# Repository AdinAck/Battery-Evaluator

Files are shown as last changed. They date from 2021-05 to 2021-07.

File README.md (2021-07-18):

# Battery-Evaluator
A comprehensive battery evaluator board for running simple tests and measurements, or creating a battery profile for accurately predicting charge level from voltage.







## Electrical Characteristics
- 0-5v battery (single cell)
- 0-1000mA programable constant current draw
- Do not reverse polarity of battery, the board will die
- While you *can* plug in a battery before USB is plugged in... you shouldn't

## Software Features
- Graph the measured and predicted battery voltage with respect to mAh consumed
- Measure ESR
- Measure mWh consumed
- Monitor temperature of FETs and resistors

## To Be Implemented
- More battery chemistries
- [Op-Amp oscillation fix](https://github.com/AdinAck/Battery-Evaluator/issues/1)
- Combine multiple constant current tests to make the ultimate battery profile
- Generate voltage, current -> percent charge function

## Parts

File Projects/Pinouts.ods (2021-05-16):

Pin ID | Type | Net
D5
D6
D9
D10
D11
D12
D13 | Dout | D13
D29
D21
A0 | DAC | MOS_SIGNAL
A1 |  | TEMP1
A2 | ADC | ~BATT
A3 | ADC | ~MOS_SOURCE
A4 |  | TEMP2
A5 | ADC | VREF
TX | UART | DATA_TX
RX | UART | DATA_RX
MOSI
MISO
SCK
D+ | USB | DEBUG_D+
D- | USB | DEBUG_D-
SWDIO | Flash
SWCLK | Flash

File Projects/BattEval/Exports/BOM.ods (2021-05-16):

Reference | Mouser Part Number | Manufacturer Name | Manufacturer Part Number | Mouser Price/Stock | Quantity
> C3, C5 | 06035A220JAT4A | AVX | 581-06035A220JAT4A | https://www.mouser.co.uk/ProductDetail/AVX/06035A220JAT4A/?qs=WmCxkUxNecQT6QFugq%2FgJA%3D%3D | 2
> C4, C7, C15 | 0603ZC105KAT2A | AVX | 581-0603ZC105KAT2A | https://www.mouser.com/Search/Refine.aspx?Keyword=581-0603ZC105KAT2A | 3
> C1, C2, C6, C8, C9, C12 | 06033C104KAT2A | AVX | 581-06033C104KAT2A | https://www.mouser.co.uk/ProductDetail/AVX/06033C104KAT2A/?qs=gPDEucxdFwYuZhv3uXRdIw%3D%3D | 6
> C10, C11 | 0603ZD106KAT4A | AVX | 581-0603ZD106KAT4A | https://www.mouser.co.uk/ProductDetail/AVX/0603ZD106KAT4A?qs=%252BdQmOuGyFcGtso703HlSDw%3D%3D | 2
> C13, C14 | 06033C470KAT2A | AVX | 581-06033C470KAT2A | http://www.mouser.com/Search/ProductDetail.aspx?qs=zRMn1EiLHUce0mcQKVYXJg%3d%3d | 2
C16 | TAJA475K010RNJV | AVX | 581-TAJA475K010RNJV | https://www.mouser.co.uk/ProductDetail/AVX/TAJA475K010RNJV?qs=VymPLiRQZITld0CPYYWYtw%3D%3D | 1
C17 | 0603ZC103KAT2A | AVX | 581-0603ZC103K | https://www.mouser.com/Search/Refine.aspx?Keyword=581-0603ZC103K | 1
> D1-D3 | MBR120VLSFT3G | ON Semiconductor | 863-MBR120VLSFT3G | https://www.mouser.co.uk/ProductDetail/ON-Semiconductor/MBR120VLSFT3G/?qs=3JMERSakebrD2yr9jFliaA%3D%3D | 3
FB1 | MI1206K601R-10 | Laird Technologies | N/A | https://www.mouser.com/Search/Refine.aspx?Keyword=N%2FA | 1
> H1, H2 | 960-23-12-D-AB-0 | Wakefield-Vette | 567-960-23-12-D-AB-0 | https://www.mouser.co.uk/ProductDetail/Wakefield-Vette/960-23-12-D-AB-0?qs=PqoDHHvF64%252BdCFngwMp09w%3D%3D | 2
IC1 | TLV9101IDBVR | Texas Instruments | 595-TLV9101IDBVR | https://www.mouser.co.uk/ProductDetail/Texas-Instruments/TLV9101IDBVR?qs=P1JMDcb91o6ZLUyc%2FHtrGA%3D%3D | 1
> IC2, IC3 | TMP235AEDBZRQ1 | Texas Instruments | 595-TMP235AEDBZRQ1 | https://www.mouser.co.uk/ProductDetail/Texas-Instruments/TMP235AEDBZRQ1/?qs=T3oQrply3y9acrBXtVPwnw%3D%3D | 2
IC4 | ATSAMD21G18A-MU | Microchip | 556-ATSAMD21G18A-MU | https://www.mouser.co.uk/ProductDetail/Microchip-Technology/ATSAMD21G18A-MU/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 | 1
IC5 | LM4040D25IDCKR | Texas Instruments | 595-LM4040D25IDCKR | https://www.mouser.co.uk/ProductDetail/Texas-Instruments/LM4040D25IDCKR?qs=paYhMW8qfivGgJ8gGFiCWw%3D%3D | 1
IC6 | FT230XS-U | FTDI Chip | 895-FT230XS-U | https://www.mouser.co.uk/ProductDetail/FTDI/FT230XS-U/?qs=Gp1Yz1mis3UZolxbXux7lw%3D%3D | 1
IC7 | SPX3819M5-L-3-3_TR | MaxLinear, Inc. | 701-SPX3819M5-L-33TR | https://www.mouser.co.uk/ProductDetail/MaxLinear/SPX3819M5-L-3-3-TR/?qs=S%2FCBhQS5rCp1Bb7a%252BD%2FCBQ%3D%3D | 1
J1 | M50-3600542 | Harwin | 855-M50-3600542 | https://www.mouser.co.uk/ProductDetail/Harwin/M50-3600542/?qs=9fQaSFfsqsz29hu1Jz0tTA%3D%3D | 1
J2 | XT60-M |  |  |  | 1
> J3, J4 | 47346-0001 | Molex | 538-47346-0001 | https://www.mouser.co.uk/ProductDetail/Molex/47346-0001/?qs=c2CV6XM0DweJBWaSeyWeCw%3D%3D | 2
LED1 | APT1608LSECK_J3-PRV | Kingbright | 604-APT1608LSECKJ3RV | https://www.mouser.co.uk/ProductDetail/Kingbright/APT1608LSECK-J3-PRV?qs=6oMev5NRZMFBN%252BbFaEKqAQ%3D%3D | 1
LED2 | 150060AS75000 | Wurth Elektronik | 710-150060AS75000 | https://www.mouser.co.uk/ProductDetail/Wurth-Elektronik/150060AS75000/?qs=d0WKAl%252BL4KbvMBYryeof0Q%3D%3D | 1
> Q1-Q4 | PH2925U,115 | Nexperia | 771-PH2925U115 | https://www.mouser.co.uk/ProductDetail/Nexperia/PH2925U115?qs=LOCUfHb8d9vnFm%2FhT%252Bjztw%3D%3D | 4
> R1, R17, R19, R22 | ERJ-S02F1002X | Panasonic | 667-ERJ-S02F1002X | https://www.mouser.co.uk/ProductDetail/Panasonic/ERJ-S02F1002X?qs=Zyl8A9hlmJre8ZnVBnn2RQ%3D%3D | 4
> R3, R16, R18 | RC0402FR-075KL | YAGEO (PHYCOMP) | 603-RC0402FR-075KL | https://www.mouser.co.uk/ProductDetail/Yageo/RC0402FR-075KL/?qs=9h0bZHM%2F3zL5adZvfm%252BR4Q%3D%3D | 3
> R4-R15 | CRGP2512F12R | TE Connectivity | 279-CRGP2512F12R | https://www.mouser.co.uk/ProductDetail/TE-Connectivity-Holsworthy/CRGP2512F12R/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 | 12
R20 | ERJ-U02F1001X | Panasonic | 667-ERJ-U02F1001X | https://www.mouser.com/Search/Refine.aspx?Keyword=667-ERJ-U02F1001X | 1
> R21, R26 | ERJ-2RKF7500X | Panasonic | 667-ERJ-2RKF7500X | https://www.mouser.com/Search/Refine.aspx?Keyword=667-ERJ-2RKF7500X | 2
R23 | ERJ-U02F1003X | Panasonic | 667-ERJ-U02F1003X | https://www.mouser.com/Search/Refine.aspx?Keyword=667-ERJ-U02F1003X | 1
> R2, R24, R25, R27, R28 | ERJ2RKD27R0X | Panasonic | 667-ERJ-2RKD27R0X | https://www.mouser.com/Search/Refine.aspx?Keyword=667-ERJ-2RKD27R0X | 5
S1 | EVQ-P9W02M | Panasonic | 667-EVQ-P9W02M | https://www.mouser.co.uk/ProductDetail/Panasonic/EVQ-P9W02M?qs=PzGy0jfpSMsvy2xbnzB8PQ%3D%3D | 1
> TP1-TP5 | TestPoint_Probe |  |  |  | 5
Y1 | CM7V-T1A-32.768kHz-6pF-20PPM-TA-QC | Micro Crystal AG | 428-201843-MG01 | https://www.mouser.co.uk/ProductDetail/Micro-Crystal/CM7V-T1A-32768kHz-6pF-20PPM-TA-QC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 | 1

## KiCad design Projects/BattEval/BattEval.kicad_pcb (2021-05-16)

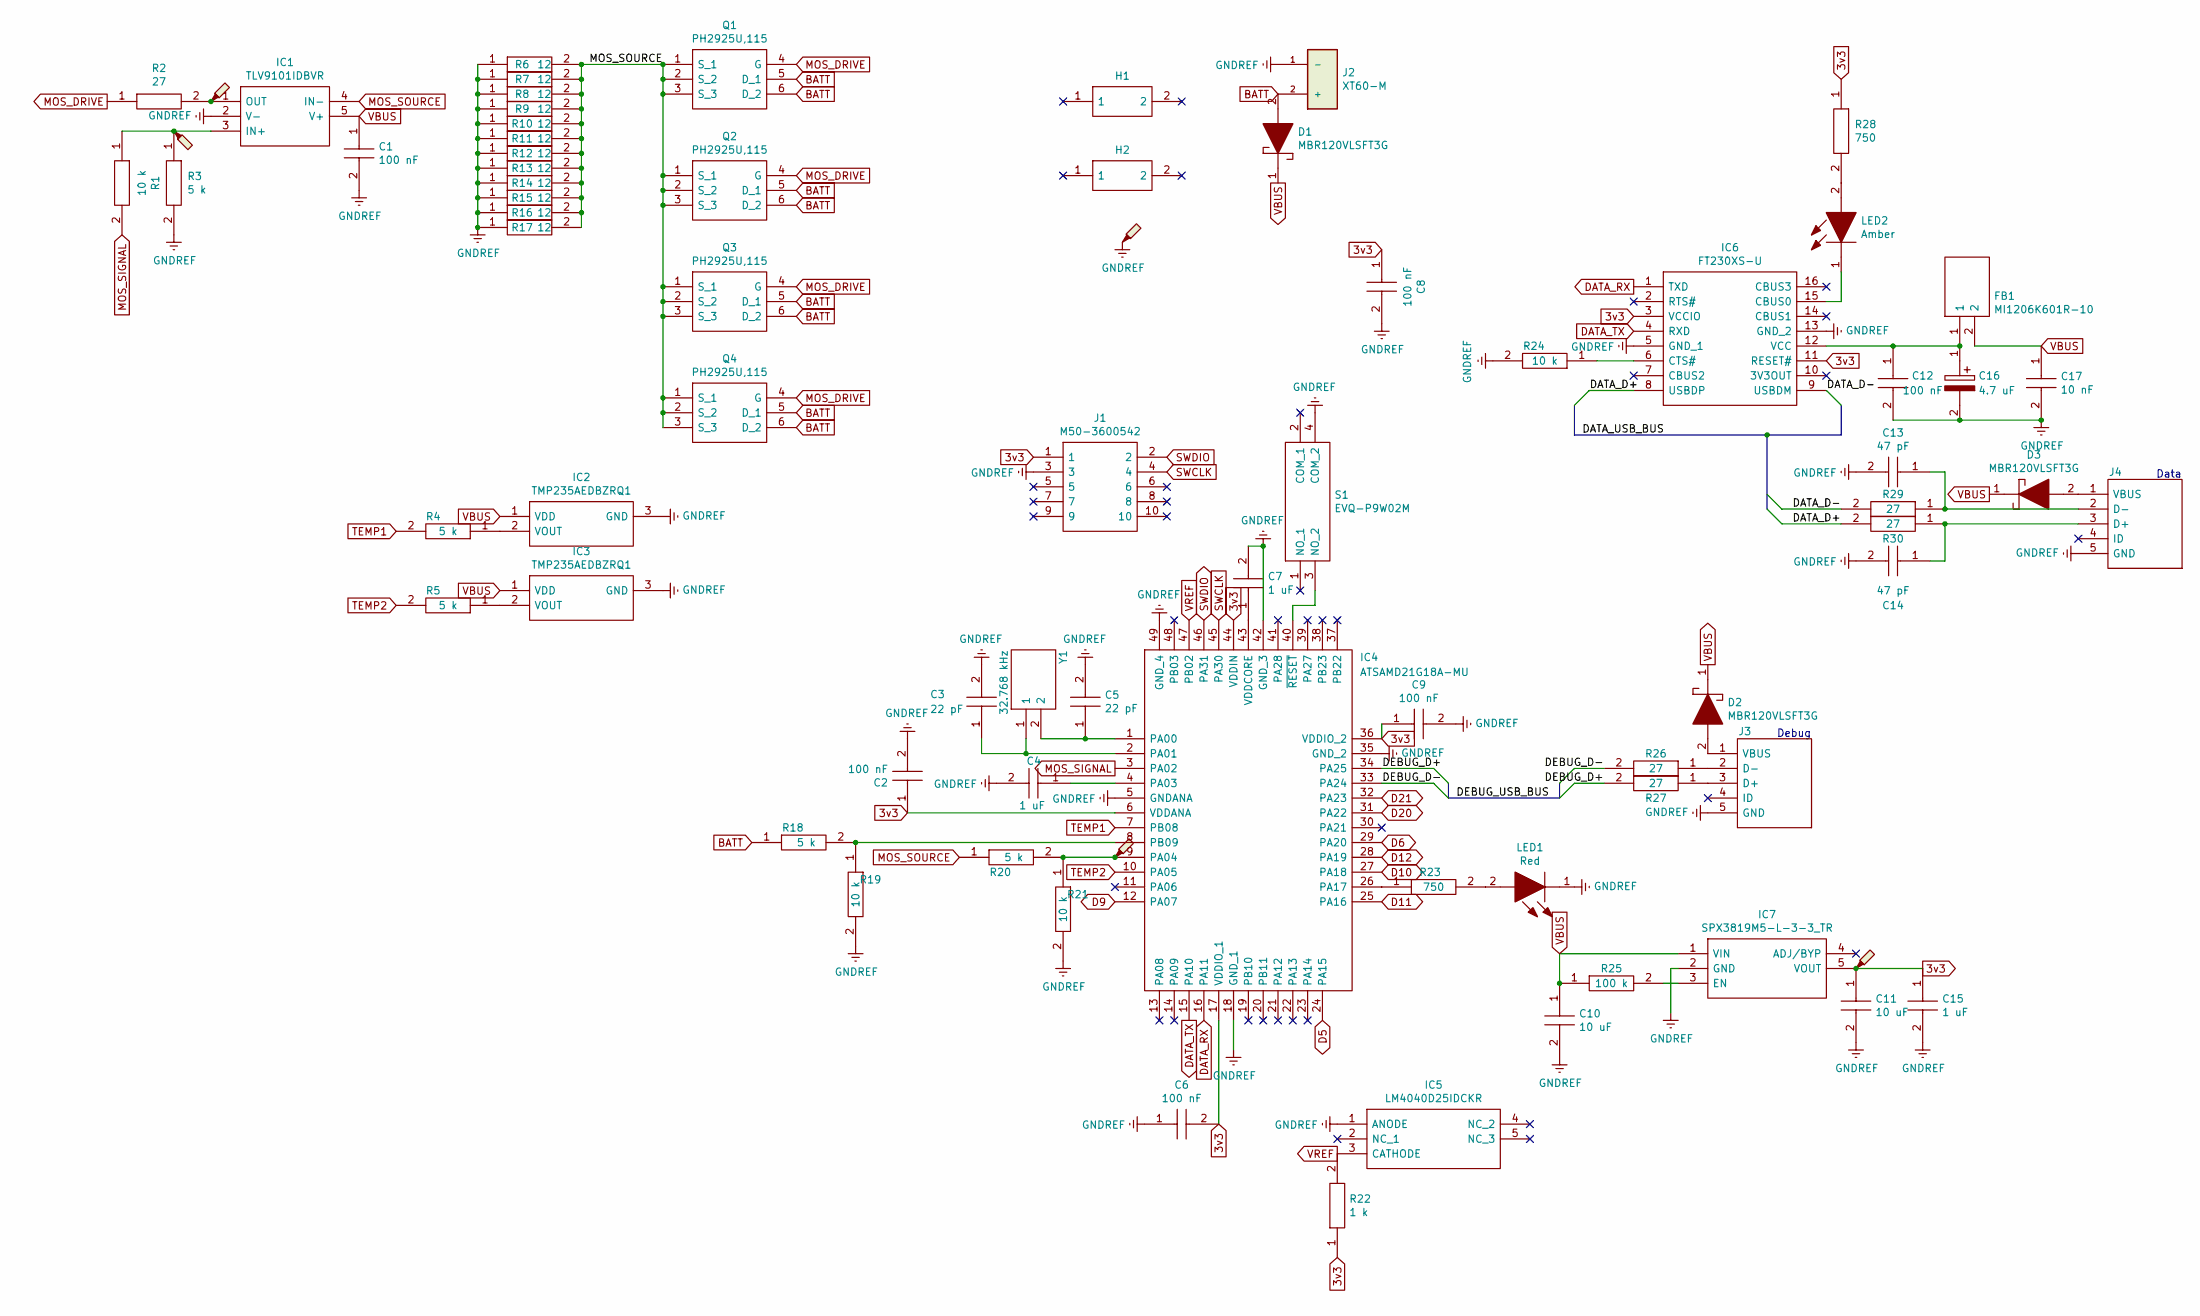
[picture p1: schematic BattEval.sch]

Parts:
C1, C2, C6, C8, C9, C12: 06033C104KAT2A; CAPC1608X90N; Mouser Part Number 581-06033C104KAT2A
C3, C5: 06035A220JAT4A; CAPC1608X90N; Mouser Part Number 581-06035A220JAT4A
C4, C7, C15: 0603ZC105KAT2A; CAPC1608X90N; Mouser Part Number 581-0603ZC105KAT2A
C10, C11: 0603ZD106KAT4A; CAPC1608X90N; Mouser Part Number 581-0603ZD106KAT4A
C13, C14: 06033C470KAT2A; CAPC1608X90N; Mouser Part Number 581-06033C470KAT2A
C16: TAJA475K010RNJV; CAPPM3216X180N; Mouser Part Number 581-TAJA475K010RNJV
C17: 0603ZC103KAT2A; CAPC1608X90N; Mouser Part Number 581-0603ZC103K
D1, D2, D3: MBR120VLSFT3G; SODFL3616X98N; Mouser Part Number 863-MBR120VLSFT3G
FB1: MI1206K601R-10; BEADC3216X130N; Mouser Part Number N/A
H1, H2: 960-23-12-D-AB-0; 9602312DAB0; Mouser Part Number 567-960-23-12-D-AB-0
IC1: TLV9101IDBVR; SOT95P280X145-5N; Mouser Part Number 595-TLV9101IDBVR
IC2, IC3: TMP235AEDBZRQ1; SOT95P237X112-3N; Mouser Part Number 595-TMP235AEDBZRQ1
IC4: ATSAMD21G18A-MU; QFN50P700X700X90-49N-D; Mouser Part Number 556-ATSAMD21G18A-MU
IC5: LM4040D25IDCKR; SOT65P210X110-5N; Mouser Part Number 595-LM4040D25IDCKR
IC6: FT230XS-U; SOP64P599X175-16N; Mouser Part Number 895-FT230XS-U
IC7: SPX3819M5-L-3-3_TR; SOT95P280X145-5N; Mouser Part Number 701-SPX3819M5-L-33TR
J1: M50-3600542; M503600542; Mouser Part Number 855-M50-3600542
J2: XT60-M; AMASS_XT60-M; PARTREV 1.2
J3, J4: 47346-0001; Mouser Part Number 538-47346-0001
LED1: APT1608LSECK_J3-PRV; APT1608CGCK; Mouser Part Number 604-APT1608LSECKJ3RV
LED2: 150060AS75000; LEDC1608X80N; Mouser Part Number 710-150060AS75000
Q1, Q2, Q3, Q4: PH2925U,115; PSMN5R660YLX; Mouser Part Number 771-PH2925U115
R1, R19, R21, R24: ERJ-S02F1002X; RESC1005X40N; Mouser Part Number 667-ERJ-S02F1002X
R2, R26, R27, R29, R30: ERJ2RKD27R0X; RESC1005X40N; Mouser Part Number 667-ERJ-2RKD27R0X
R3, R4, R5, R18, R20: RC0402FR-075KL; RESC1005X40N; Mouser Part Number 603-RC0402FR-075KL
R6, R7, R8, R9, R10, R11, R12, R13, R14, R15, R16, R17: CRGP2512F12R; RESC6432X65N; Mouser Part Number 279-CRGP2512F12R
R22: ERJ-U02F1001X; RESC1005X40N; Mouser Part Number 667-ERJ-U02F1001X
R23, R28: ERJ-2RKF7500X; RESC1005X40N; Mouser Part Number 667-ERJ-2RKF7500X
R25: ERJ-U02F1003X; RESC1005X40N; Mouser Part Number 667-ERJ-U02F1003X
S1: EVQ-P9W02M; EVQP9W02M; Mouser Part Number 667-EVQ-P9W02M
TP1, TP2, TP3, TP4, TP5: TestPoint_Probe; Standard_Probe_Point
Y1: CM7V-T1A-32.768kHz-6pF-20PPM-TA-QC; CM7VT1A32768kHz6pF20PPMTAQC; Mouser Part Number 428-201843-MG01

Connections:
3v3: C2.1, C6.2, C8.1, C9.1, C11.1, C15.1, IC4.6 (VDDANA), IC4.17 (VDDIO_1), IC4.36 (VDDIO_2), IC4.44 (VDDIN), IC6.3 (VCCIO), IC6.11 (RESET#), IC7.5 (VOUT), J1.1, R22.1, R28.1, TP5.1
/DATA_D+: IC6.8 (USBDP), R30.2
/DATA_D-: IC6.9 (USBDM), R29.2
/DEBUG_D+: IC4.34 (PA25), R27.2
/DEBUG_D-: IC4.33 (PA24), R26.2
BATT: D1.2, J2.2 (+), Q1.5 (D_1), Q1.6 (D_2), Q2.5 (D_1), Q2.6 (D_2), Q3.5 (D_1), Q3.6 (D_2), Q4.5 (D_1), Q4.6 (D_2), R18.1
D5: IC4.24 (PA15)
D6: IC4.29 (PA20)
D9: IC4.12 (PA07)
D10: IC4.27 (PA18)
D11: IC4.25 (PA16)
D12: IC4.28 (PA19)
D20: IC4.31 (PA22)
D21: IC4.32 (PA23)
DATA_RX: IC4.16 (PA11), IC6.1 (TXD)
DATA_TX: IC4.15 (PA10), IC6.4 (RXD)
GNDREF: C1.2, C2.2, C3.2, C4.2, C5.2, C6.1, C7.2, C8.2, C9.2, C10.2, C11.2, C12.2, C13.2, C14.2, C15.2, C16.2, C17.2, IC1.2 (V-), IC2.3 (GND), IC3.3 (GND), IC4.5 (GNDANA), IC4.18 (GND_1), IC4.35 (GND_2), IC4.42 (GND_3), IC4.49 (GND_4), IC5.1 (ANODE), IC6.5 (GND_1), IC6.13 (GND_2), IC7.2 (GND), J1.3, J2.1 (-), J3.5 (GND), J4.5 (GND), LED1.1, R3.2, R6.1, R7.1, R8.1, R9.1, R10.1, R11.1, R12.1, R13.1, R14.1, R15.1, R16.1, R17.1, R19.2, R21.2, R24.2, S1.4 (COM_2), TP4.1
MOS_DRIVE: Q1.4 (G), Q2.4 (G), Q3.4 (G), Q4.4 (G), R2.1
MOS_SIGNAL: IC4.3 (PA02), R1.2
MOS_SOURCE: IC1.4 (IN-), Q1.1 (S_1), Q1.2 (S_2), Q1.3 (S_3), Q2.1 (S_1), Q2.2 (S_2), Q2.3 (S_3), Q3.1 (S_1), Q3.2 (S_2), Q3.3 (S_3), Q4.1 (S_1), Q4.2 (S_2), Q4.3 (S_3), R6.2, R7.2, R8.2, R9.2, R10.2, R11.2, R12.2, R13.2, R14.2, R15.2, R16.2, R17.2, R20.1
unnamed: C3.1, IC4.2 (PA01), Y1.1
unnamed: C4.1, IC4.4 (PA03)
unnamed: C5.1, IC4.1 (PA00), Y1.2
unnamed: C7.1, IC4.43 (VDDCORE)
unnamed: C12.1, C16.1, FB1.1, IC6.12 (VCC)
unnamed: C13.1, J4.2 (D-), R29.1
unnamed: C14.1, J4.3 (D+), R30.1
unnamed: D2.2, J3.1 (VBUS)
unnamed: D3.2, J4.1 (VBUS)
unnamed: IC1.1 (OUT), R2.2, TP2.1
unnamed: IC1.3 (IN+), R1.1, R3.1, TP1.1
unnamed: IC2.2 (VOUT), R4.1
unnamed: IC3.2 (VOUT), R5.1
unnamed: IC4.8 (PB09), R18.2, R19.1
unnamed: IC4.9 (PA04), R20.2, R21.1, TP3.1
unnamed: IC4.26 (PA17), R23.1
unnamed: IC4.40 (~RESET), S1.3 (NO_2)
unnamed: IC6.6 (CTS#), R24.1
unnamed: IC6.15 (CBUS0), LED2.1
unnamed: IC7.3 (EN), R25.2
unnamed: J3.2 (D-), R26.1
unnamed: J3.3 (D+), R27.1
unnamed: LED1.2, R23.2
unnamed: LED2.2, R28.2
SWCLK: IC4.45 (PA30), J1.4
SWDIO: IC4.46 (PA31), J1.2
TEMP1: IC4.7 (PB08), R4.2
TEMP2: IC4.10 (PA05), R5.2
VBUS: C1.1, C10.1, C17.1, D1.1, D2.1, D3.1, FB1.2, IC1.5 (V+), IC2.1 (VDD), IC3.1 (VDD), IC7.1 (VIN), R25.1
VREF: IC4.47 (PB02), IC5.3 (CATHODE), R22.2

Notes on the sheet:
Debug
Data

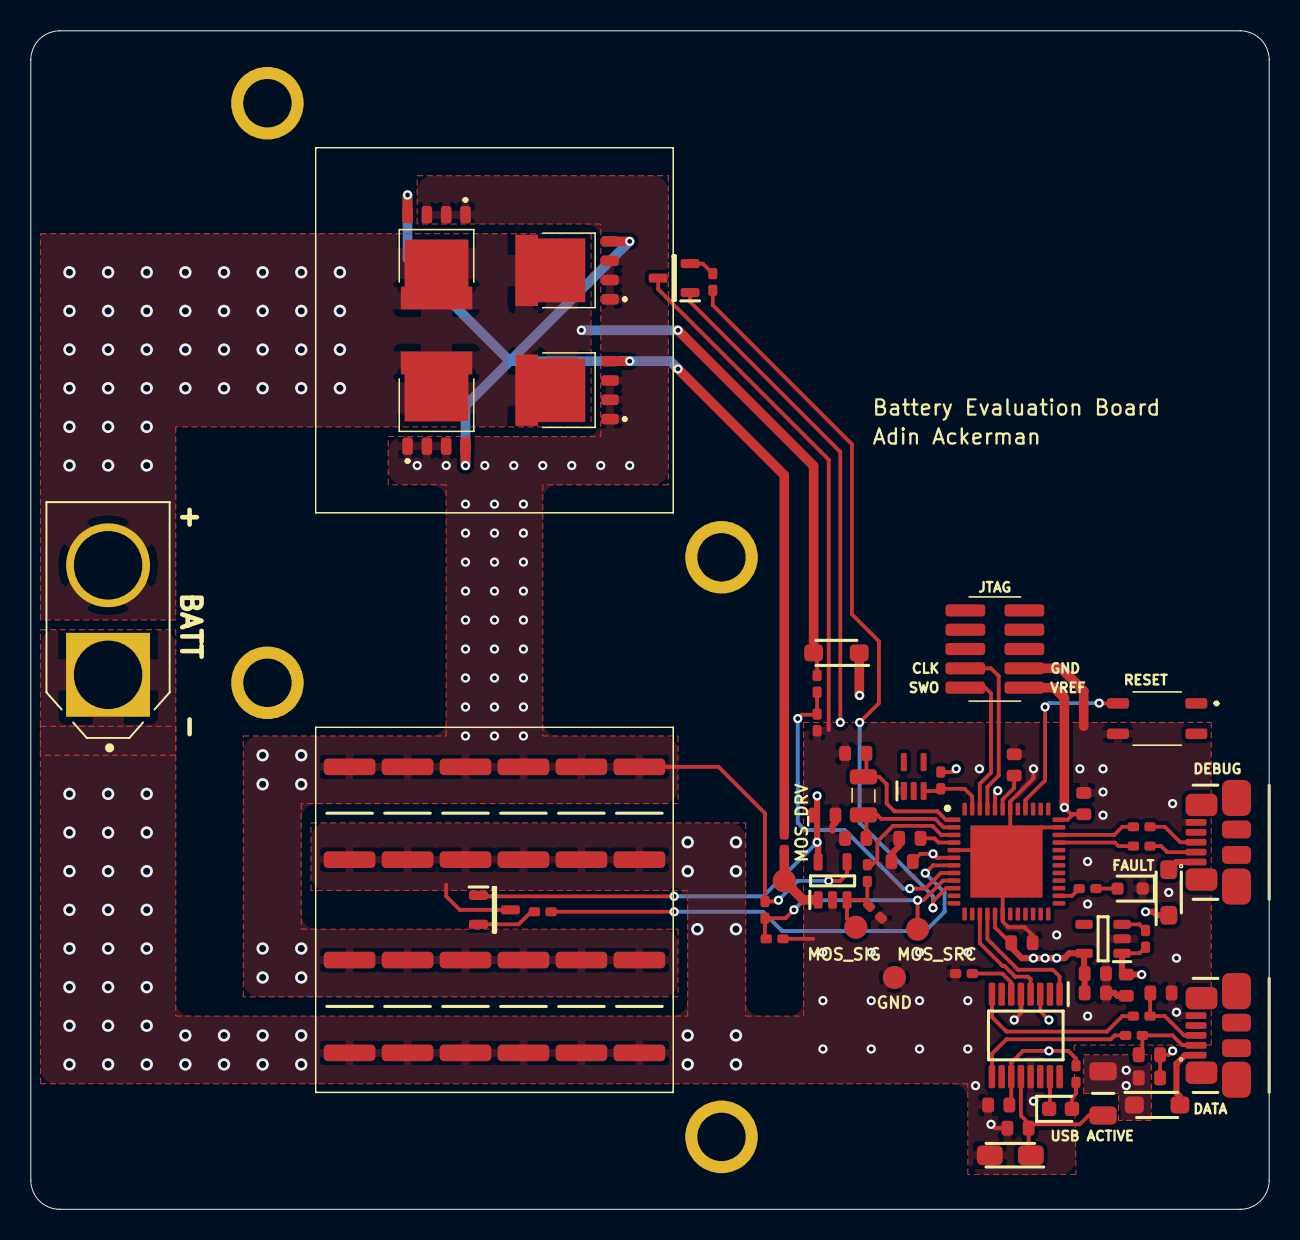
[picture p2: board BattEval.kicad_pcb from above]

Board: 2 copper layers, 81.4 x 77.5 mm, 77 parts (1 on the bottom side), 42 nets.

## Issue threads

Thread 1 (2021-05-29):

Op-Amp Oscillation Fix

AdinAck, 2021-05-29:
- Add 100nF capacitor from OUT to IN-
- Add 220 Ohm resistor from IN- to MOS_SOURCE

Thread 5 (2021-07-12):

Thermal throttle

AdinAck, 2021-07-12:
I recently discovered that lithium batteries can in fact overheat the MOSFETs if the target current is high enough, so I need to add thermal throttling.

I should implement thermal throttling board-side to ensure that if for whatever reason the client stops working, the board will not catch on fire.

The client should of course be informed when thermal throttling occurs so it can be displayed to the user.

While on the topic of temperature, maybe a "high ambient temperature" warning would be nice as well.

AdinAck, 2021-07-14:
Integrated thermal throttling and high ambient temperature warning added in eb28f56820dc9e42cb6b371c12010c0a3b3db2d6.

AdinAck, 2021-07-15:
Fully implemented.

Added warnings in 1a29615d5b73f9eea2b5b29dc64983564c6e26e0.

Closed 2021-07-15.

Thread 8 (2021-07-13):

Temperature sensor has frequent errors

AdinAck, 2021-07-13:
The temperature sensor's reading will frequently dip by a few degrees for a single measurement... why?

AdinAck, 2021-07-14:
Resolved by returning median of sample measurements rather than each measurement in eb28f56820dc9e42cb6b371c12010c0a3b3db2d6.

Closed 2021-07-14.

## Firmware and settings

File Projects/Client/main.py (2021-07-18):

"""
Battery Evaluator Client

This code is garbage, do not replicate for your own good.

Yours truly,
Adin Ackerman
"""

import threading
import serial
from serial.tools import list_ports
from serial.serialutil import SerialException
from tkinter import messagebox
from tkinter import *
from tkinter.ttk import *
import matplotlib.pyplot as plt
from matplotlib.backends.backend_tkagg import FigureCanvasTkAgg
from queue import Queue
from time import time, time_ns, sleep
from datetime import timedelta
from typing import *

COMMAND_DICT = {
    "batt-voltage": 0x10,
    "current": 0x11,
    # 'temp1': 0x12,
    "temp2": 0x13,
    "set-current": 0x20,
    "set-power": 0x21,
}

BATT_CHEMS = {"Lithium": (3, 4.1), "Alkaline": (1.2, 1.5), "Custom": (5, 5)}

THROTTLE_TEMP = 50
SHUTDOWN_TEMP = 60

tasksReady = threading.Condition()
taskQueue = Queue()


class TaskResult:
    value: Any = None


def ioTask(f):
    def inner(*args):
        condition = threading.Condition()
        result = TaskResult()
        with tasksReady:
            tasksReady.notify()

        with condition:
            taskQueue.put((result, condition, lambda: f(*args)))
            condition.wait()

        return result.value

    return inner


def ioLoop():
    while True:
        r, c, task = taskQueue.get()
        try:
            r.value = task()
        except SerialException:
            msg = "Communication interrupted."
            messagebox.showerror("Error", msg)
            updateStatus("[ERROR] " + msg)
            disconnect()
        with c:
            c.notify()


class SerCom:
    connected = False
    ports = {
        str(d.description): d for d in list_ports.comports() if d.description != "n/a"
    }

    def connect(self, comport: str) -> None:
        self.com = serial.Serial(self.ports[comport].device, 9600)
        self.connected = True

    def close(self):
        self.com.close()
        self.conected = False

    @property
    @ioTask
    def battVoltage(self) -> float:
        self.com.write(bytes([COMMAND_DICT["batt-voltage"], 0]))
        msgLen = int.from_bytes(self.com.read(1), "big")
        battv = self.com.read(msgLen).decode()
        battv = round(float(battv), 3)

        return battv

    @property
    @ioTask
    def battCurrent(self) -> float:
        self.com.write(bytes([COMMAND_DICT["current"], 0]))
        msgLen = int.from_bytes(self.com.read(1), "big")
        current = self.com.read(msgLen).decode()
        current = int(round(float(current) * 1000, 3))  # mA

        return current

    @battCurrent.setter
    @ioTask
    def battCurrent(self, value: int) -> None:
        msg = int.to_bytes(value, 2, "big")
        self.com.write(bytes([COMMAND_DICT["set-current"], 2]))
        self.com.write(msg)
        print("set-current", value)

    @property
    @ioTask
    def battPower(self) -> float:
        return self.battCurrent * self.battVoltage

    @battPower.setter
    @ioTask
    def battPower(self, value: int) -> None:
        msg = int.to_bytes(value, 2, "big")
        self.com.write(bytes([COMMAND_DICT["set-power"], 2]))
        self.com.write(msg)
        print("set-power", value)

    @property
    @ioTask
    def resistorTemp(self) -> float:
        self.com.write(bytes([COMMAND_DICT["temp1"], 0]))
        msgLen = int.from_bytes(self.com.read(1), "big")
        temp = self.com.read(msgLen).decode()
        temp = round(float(temp), 1)  # C

        return temp

    @property
    @ioTask
    def FETTemp(self) -> float:
        self.com.write(bytes([COMMAND_DICT["temp2"], 0]))
        msgLen = int.from_bytes(self.com.read(1), "big")
        temp = self.com.read(msgLen).decode()
        temp = round(float(temp), 1)  # C

        return temp


class BattEval:
    def __init__(self):
        self.battVoltage = 0
        self.battCurrent = 0
        self.FETTemp = 0

        self.battESR = 0

        self.battVoltageHistory = []
        self.adjustedBattVoltageHistory = []
        self.currentHistory = []
        self.powerHistory = []
        self.timeHistory = []
        self.temp2History = []
        self.mAhHistory = []
        self.mWhHistory = []

        self.mAh = 0
        self.mWh = 0

        self.ableToTest = False
        self.belowStopPointCount = 0
        self.throttling = False

        self.lock = threading.Lock()

    def start(self) -> None:
        self.thread = threading.Thread(target=self.main, daemon=True)
        self.thread.start()

    def main(self) -> None:
        global startTime

        start: Optional[float] = None

        while ser.connected:
            with self.lock:
                self.battVoltage = ser.battVoltage
                self.battCurrent = ser.battCurrent
                self.FETTemp = ser.FETTemp

            if not self.throttling and self.FETTemp > THROTTLE_TEMP:
                self.throttling = True
                updateStatus("[WARNING] Thermal throttling.")
                temp2Value["foreground"] = "orange"
            elif self.throttling and self.FETTemp < THROTTLE_TEMP:
                self.throttling = False
                updateStatus("No longer thermal throttling.")
                temp2Value["foreground"] = "white"
            elif self.FETTemp > SHUTDOWN_TEMP:
                updateStatus("[WARNING] Shutdown temperature reached.")
                temp2Value["foreground"] = "red"
            FETTempString.set(f"{self.FETTemp}C")

            # battery voltage stuff
            if self.battVoltage > 0.1:
                battVoltageValue["foreground"] = "green"
                battString.set(f"{self.battVoltage}v")
                currentString.set(f"{self.battCurrent}mA")
                if start is not None:
                    dt = time_ns() - start  # ns
                else:
                    dt = 0
                # mA * ns * (s / (10**9) ns) * (h / 3600 s) = mAh
                self.mAh += self.battCurrent * dt / 10 ** (9) / 3600
                # mA * V * ns * (s / (10**9) ns) * (h / 3600 s) = mWh
                self.mWh += self.battCurrent * self.battVoltage * dt / 10 ** (9) / 3600
                start = time_ns()

                mAhString.set(f"{round(self.mAh, 1)}")
                mWhString.set(f"{round(self.mWh, 1)}")

                offset = self.battESR * self.battCurrent / 1000

                doUpdate = False

                # A constant current test is running
                if runningTest == "Current":
                    if int(self.mAh) not in self.mAhHistory:
                        doUpdate = True

                # A constant power test is running
                elif runningTest == "Power":
                    if int(self.mWh) not in self.mWhHistory:
                        doUpdate = True

                # A test is running
                if runningTest is not None:
                    if doUpdate:
                        self.battVoltageHistory.append(self.battVoltage)
                        self.adjustedBattVoltageHistory.append(
                            self.battVoltage + offset
                        )
                        self.currentHistory.append(self.battCurrent)
                        self.powerHistory.append(self.battCurrent * self.battVoltage)
                        self.temp2History.append(self.FETTemp)
                        self.mAhHistory.append(int(self.mAh))
                        self.mWhHistory.append(int(self.mWh))
                        self.timeHistory.append(round(time() - startTime))
                        if not plotUpdating and root.focus_displayof() is not None:
                            threading.Thread(target=updatePlot).start()

                    timeString.set(str(timedelta(seconds=round(time() - startTime))))

                    if self.battVoltage + offset < BATT_CHEMS[chemString.get()][0]:
                        self.belowStopPointCount += 1
                    else:
                        self.belowStopPointCount = 0

                    if self.belowStopPointCount > 10:
                        stopTest()

                if chemString.get() != "-":
                    if not self.ableToTest:
                        ready()
                        self.ableToTest = True
                else:
                    if self.ableToTest:
                        notReady()
                        self.ableToTest = False

            else:
                battVoltageValue["foreground"] = "red"
                battString.set("No Battery Connected")
                if self.ableToTest:
                    notReady()
                    self.ableToTest = False

            if chemString.get() == "Custom":
                startLabel["state"] = "normal"
                startValue["state"] = "normal"
                endLabel["state"] = "normal"
                endValue["state"] = "normal"
            elif chemString.get() != "-":
                startLabel["state"] = "disabled"
                startValue["state"] = "disabled"
                endLabel["state"] = "disabled"
                endValue["state"] = "disabled"
                startString.set(BATT_CHEMS[chemString.get()][1])
                endString.set(BATT_CHEMS[chemString.get()][0])


def updatePlot():
    global plotUpdating, test, history, axisLabel

    plotUpdating = True
    for ax in axs.flat:
        ax.cla()
        ax.grid(color="grey")

    axs[0, 0].plot(history, board.battVoltageHistory, label="Measured")
    axs[0, 0].plot(history, board.adjustedBattVoltageHistory, label="Adjusted")
    axs[0, 0].legend()
    axs[0, 1].plot(history, board.temp2History, label="FET", color="tab:olive")
    axs[0, 1].legend()
    axs[1, 0].plot(history, board.currentHistory, color="tab:green")
    axs[1, 1].plot(history, board.powerHistory, color="tab:purple")
    axs[2, 0].plot(
        board.timeHistory if test else history, board.mAhHistory, color="tab:red"
    )
    axs[2, 1].plot(
        history if test else board.timeHistory, board.mWhHistory, color="tab:pink"
    )

    axs[0, 0].set_title("Batt Voltage", color="white")
    axs[0, 1].set_title("Temperatures", color="white")
    axs[1, 0].set_title("Current Draw", color="white")
    axs[1, 1].set_title("Power Draw", color="white")
    axs[2, 0].set_title("Capacity (mAh)", color="white")
    axs[2, 1].set_title("Capacity (mWh)", color="white")

    axs[0, 0].set_xlabel(axisLabel, color="white")
    axs[0, 0].set_ylabel("Volts", color="white")
    axs[0, 1].set_xlabel(axisLabel, color="white")
    axs[0, 1].set_ylabel("Degrees (C)", color="white")
    axs[1, 0].set_xlabel(axisLabel, color="white")
    axs[1, 0].set_ylabel("mA", color="white")
    axs[1, 1].set_xlabel(axisLabel, color="white")
    axs[1, 1].set_ylabel("mW", color="white")
    axs[2, 0].set_xlabel("Time (s)" if test else axisLabel, color="white")
    axs[2, 0].set_ylabel("mAh", color="white")
    axs[2, 1].set_xlabel(axisLabel if test else "Time (s)", color="white")
    axs[2, 1].set_ylabel("mWh", color="white")

    fig.tight_layout(pad=1)

    canvas.draw_idle()

    plotUpdating = False


def connect():
    ser.connect(comportString.get())
    connectButton["command"] = lambda: threading.Thread(target=disconnect).start()
    connectButton["text"] = "Disconnect"
    battVoltageLabel["state"] = "normal"
    battVoltageValue["state"] = "normal"
    temp2Label["state"] = "normal"
    temp2Value["state"] = "normal"
    battChemLabel["state"] = "normal"
    battChemDrop["state"] = "normal"

    board.start()

    updateStatus("Connection established.")


def disconnect():
    ser.connected = False
    board.thread.join()
    ser.close()
    connectButton["command"] = connect
    connectButton["text"] = "Connect"

    battString.set("")
    currentString.set("")
    FETTempString.set("")
    mAhString.set("")
    mWhString.set("")
    chemString.set("-")

    battVoltageLabel["state"] = "disabled"
    battVoltageValue["state"] = "disabled"
    currentLabel["state"] = "disabled"
    currentValue["state"] = "disabled"
    # ser.resistorTempString.set("")
    # temp1Label['state'] = 'disabled'
    # temp1Value['state'] = 'disabled'
    temp2Label["state"] = "disabled"
    temp2Value["state"] = "disabled"
    mAhLabel["state"] = "disabled"
    mAhValue["state"] = "disabled"
    mWhLabel["state"] = "disabled"
    mWhValue["state"] = "disabled"
    ESRString.set("")
    ESRLabel["state"] = "disabled"
    ESRValue["state"] = "disabled"

    battChemLabel["state"] = "disabled"
    battChemDrop["state"] = "disabled"
    getESRButton["state"] = "disabled"
    startLabel["state"] = "disabled"
    startValue["state"] = "disabled"
    endLabel["state"] = "disabled"
    endValue["state"] = "disabled"
    constCurntLabel["state"] = "disabled"
    constCurntValue["state"] = "disabled"
    constCurntStartButton["state"] = "disabled"
    constPwrLabel["state"] = "disabled"
    constPwrValue["state"] = "disabled"
    constPwrStartButton["state"] = "disabled"
    resetButton["state"] = "disabled"

    board.ableToTest = False

    updateStatus("Disconnected.")


def ready():
    getESRButton["state"] = "normal"
    constCurntLabel["state"] = "normal"
    constCurntValue["state"] = "normal"
    constCurntStartButton["state"] = "normal"
    constPwrLabel["state"] = "normal"
    constPwrValue["state"] = "normal"
    constPwrStartButton["state"] = "normal"
    resetButton["state"] = "normal"

    currentLabel["state"] = "normal"
    currentValue["state"] = "normal"
    mAhLabel["state"] = "normal"
    mAhValue["state"] = "normal"
    mWhLabel["state"] = "normal"
    mWhValue["state"] = "normal"

    updateStatus("Ready to run tests.")


def notReady():
    getESRButton["state"] = "disabled"
    startLabel["state"] = "disabled"
    startValue["state"] = "disabled"
    endLabel["state"] = "disabled"
    endValue["state"] = "disabled"
    constCurntLabel["state"] = "disabled"
    constCurntValue["state"] = "disabled"
    constCurntStartButton["state"] = "disabled"
    constPwrLabel["state"] = "disabled"
    constPwrValue["state"] = "disabled"
    constPwrStartButton["state"] = "disabled"
    resetButton["state"] = "disabled"

    currentString.set("")
    mAhString.set("")
    mWhString.set("")

    currentLabel["state"] = "disabled"
    currentValue["state"] = "disabled"
    mAhLabel["state"] = "disabled"
    mAhValue["state"] = "disabled"
    mWhLabel["state"] = "disabled"
    mWhValue["state"] = "disabled"

    updateStatus("Not ready to run tests, ensure battery is connected.")


def getESR(current=900, depth=50):
    updateStatus("Determining ESR...")
    with board.lock:
        ser.battCurrent = 0
        startV = []
        endV = []

        popup = Toplevel()
        popup.geometry("500x100")
        Label(popup, text="Determining ESR").pack(side=TOP)

        progress = 0
        progress_var = IntVar()
        progress_bar = Progressbar(popup, variable=progress_var, maximum=depth * 2 + 25)
        progress_bar.pack(fill=X, expand=1, side=BOTTOM, padx=10, pady=10)
        popup.pack_slaves()

        for _ in range(depth):
            startV.append(ser.battVoltage)
            progress += 1
            progress_var.set(progress)

        ser.battCurrent = current
        i = 0
        while (c := ser.battCurrent) < current:
            if i > 25:
                ESRValue["foreground"] = "red"
                ESRString.set("Fault")
                popup.destroy()
                popup.update()
                messagebox.showerror("Error", "Device is not functioning properly.")
                ser.battCurrent = 0
                return

            progress += 1
            progress_var.set(progress)

            i += 1
        for _ in range(depth):
            endV.append(ser.battVoltage)
            progress += 1
            progress_var.set(progress)

        ser.battCurrent = 0

    result = round(
        (sorted(startV)[depth // 2] - sorted(endV)[depth // 2]) * (1000 / current), 3
    )

    ESRLabel["state"] = "normal"

    if result > 0:
        ESRValue["foreground"] = "white"
        ESRString.set(f"{int(result * 1000)} mOhms")
        board.battESR = result
    else:
        ESRValue["foreground"] = "red"
        ESRString.set("Fault")
        messagebox.showerror("Error", "Device is not functioning properly.")

    popup.destroy()
    popup.update()
    updateStatus("Done.")


def startTest(mode: str) -> None:
    global runningTest

    comDropLabel["state"] = "disabled"
    comDrop["state"] = "disabled"
    connectButton["state"] = "disabled"
    battChemLabel["state"] = "disabled"
    battChemDrop["state"] = "disabled"
    getESRButton["state"] = "disabled"
    resetButton["state"] = "disabled"

    for ax in axs.flat:
        ax.clear()

    if chemString.get() == "Custom":
        BATT_CHEMS["Custom"] = float(endString.get()), float(startString.get())

    if ser.battVoltage < BATT_CHEMS[chemString.get()][1]:
        msg = "Battery not full, test may be inconclusive."
        messagebox.showwarning("Warning", msg)
        updateStatus(f"[WARNING] {msg}")

    if board.FETTemp > 40:
        msg = "High ambient temperature, power draw may be limited."
        messagebox.showwarning("Warning", msg)
        updateStatus(f"[WARNING] {msg}")

    board.battVoltageHistory = []
    board.adjustedBattVoltageHistory = []
    board.currentHistory = []
    board.powerHistory = []
    # ser.temp1History = []
    board.temp2History = []
    board.mAhHistory = []
    board.mWhHistory = []
    board.timeHistory = []

    updateStatus("Test started.")
    runningTest = mode
    updateAxisLabel()


def startConstCurntDraw():
    global startTime, stopTest
    constCurntStartButton["text"] = "Working"
    constCurntStartButton["state"] = "disabled"
    constCurntValue["state"] = "disabled"
    constPwrStartButton["state"] = "disabled"
    constPwrValue["state"] = "disabled"
    ESRValue["state"] = "disabled"
    if ESRString.get() == "":
        getESR()
    ESRValue["state"] = "normal"
    timeLabel["state"] = "normal"
    timeValue["state"] = "normal"

    if ESRString.get() != "Fault":
        startTest("Current")

        startTime = time()

        ser.battCurrent = int(constCurntString.get())
        constCurntStartButton["state"] = "nornmal"
        constCurntStartButton["text"] = "Stop"
        stopTest = stopConstCurntDraw
        constCurntStartButton["command"] = stopTest
    else:
        constCurntStartButton["state"] = "nornmal"
        constCurntStartButton["text"] = "Start"


def stopConstCurntDraw():
    global runningTest
    ser.battCurrent = 0
    constCurntStartButton["text"] = "Start"
    constCurntStartButton["command"] = lambda: threading.Thread(
        target=startConstCurntDraw
    ).start()
    comDropLabel["state"] = "normal"
    comDrop["state"] = "normal"
    connectButton["state"] = "normal"
    getESRButton["state"] = "normal"
    constCurntValue["state"] = "normal"
    constPwrStartButton["state"] = "normal"
    constPwrValue["state"] = "normal"
    resetButton["state"] = "normal"

    updateStatus("Test ended.")
    runningTest = None


def startConstPwrDraw():
    global startTime, stopTest
    constPwrStartButton["text"] = "Working"
    constPwrStartButton["state"] = "disabled"
    constPwrValue["state"] = "disabled"
    constCurntStartButton["state"] = "disabled"
    constCurntValue["state"] = "disabled"
    ESRValue["state"] = "disabled"
    if ESRString.get() == "":
        getESR()

    if ESRString.get() != "Fault":
        ESRValue["state"] = "normal"
        timeLabel["state"] = "normal"
        timeValue["state"] = "normal"

        startTest("Power")

        startTime = time()

        ser.battPower = int(constPwrString.get())
        constPwrStartButton["state"] = "nornmal"
        constPwrStartButton["text"] = "Stop"
        stopTest = stopConstPwrDraw
        constPwrStartButton["command"] = stopTest
    else:
        constPwrStartButton["state"] = "nornmal"
        constPwrStartButton["text"] = "Start"


def stopConstPwrDraw():
    global runningTest
    ser.battCurrent = 0
    constPwrStartButton["text"] = "Start"
    constPwrStartButton["command"] = lambda: threading.Thread(
        target=startConstPwrDraw
    ).start()
    comDropLabel["state"] = "normal"
    comDrop["state"] = "normal"
    connectButton["state"] = "normal"
    getESRButton["state"] = "normal"
    constPwrValue["state"] = "normal"
    constCurntStartButton["state"] = "normal"
    constCurntValue["state"] = "normal"
    resetButton["state"] = "normal"

    updateStatus("Test ended.")
    runningTest = None


stopTest = lambda: None


def updateStatus(msg: str) -> None:
    status.append(msg)
    if len(status) > 5:
        status.pop(0)
    statusString.set("\n".join(status))


def updateAxisLabel():
    global test, history, axisLabel
    test = runningTest == "Current"

    history = board.mAhHistory if test else board.mWhHistory
    axisLabel = "mAh" if test else "mWh"


def resetCumulatives() -> None:
    board.mAh = 0
    board.mWh = 0


startTime = time()
status: List[str] = [""] * 5
runningTest = None
plotUpdating = False

ser = SerCom()

threading.Thread(target=ioLoop, daemon=True).start()

# set up gui
root = Tk()
root.title("Battery Evaluator Client")

comportString = StringVar()
chemString = StringVar()
startString = StringVar()
endString = StringVar()
constCurntString = StringVar()
constPwrString = StringVar()
battString = StringVar()
currentString = StringVar()
resistorTempString = StringVar()
FETTempString = StringVar()
mAhString = StringVar()
mWhString = StringVar()
ESRString = StringVar()
timeString = StringVar()
statusString = StringVar()

board = BattEval()

main = Frame(root)
main.pack(fill=BOTH, expand=True)
main.grid_columnconfigure(0, weight=1)
main.grid_columnconfigure(1, weight=1)
main.grid_columnconfigure(2, weight=1)
main.grid_rowconfigure(0, weight=1)
main.grid_rowconfigure(1, weight=1)

left = Frame(main)
left.grid(row=0, column=0, padx=5, pady=5, sticky="NW")
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

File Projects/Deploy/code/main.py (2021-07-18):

from board import *
from busio import UART
from digitalio import DigitalInOut, Direction
from analogio import AnalogIn, AnalogOut

COMMAND_DICT = {
    "batt-voltage": 0x10,
    "current": 0x11,
    # 'temp1': 0x12,
    "temp2": 0x13,
    "set-current": 0x20,
    "set-power": 0x21,
}

MODE = "idle"
THROTTLE_TEMP = 50
SHUTDOWN_TEMP = 60
MAX_POWER = 4

# Pinouts
uart = UART(TX, RX, baudrate=9600)  # UART
faultLed = DigitalInOut(D13)  # Fault LED
faultLed.direction = Direction.OUTPUT
vref = AnalogIn(A5)  # Voltage reference
mos = AnalogOut(A0)  # Mos signal (op-amp)
batt = AnalogIn(A2)  # Battery voltage
current = AnalogIn(A3)  # Current measure
# temp1 = AnalogIn(A1)
temp2 = AnalogIn(A4)  # Temperature measure 2

targetCurrent = 0
targetPower = 0
outputCurrent = 0

watchdog = 0
output = 0
powerLimit = MAX_POWER


def getVoltage(pin):
    return (pin.value / vref.value) * 2.5
    # return pin.value / (2**16) * 3.3


def getMeasurement(pin, factor=1, offset=0):
    return getVoltage(pin) * factor + offset


def sendMeasurement(msg):

    uart.write(memoryview(bytes([len(msg)])))

    uart.write(memoryview(bytes([ord(char) for char in msg])))


def calculatePowerLimit(temp):
    a = targetPower / (
        (SHUTDOWN_TEMP - THROTTLE_TEMP) * (THROTTLE_TEMP - SHUTDOWN_TEMP)
    )
    return a * (temp - 2 * THROTTLE_TEMP + SHUTDOWN_TEMP) * (temp - SHUTDOWN_TEMP)


# Main loop
while True:
    battValue = getMeasurement(batt, 1.47)
    currentValue = getMeasurement(current, 1.47)
    temp2Value = sorted([getMeasurement(temp2, 100, -50) for _ in range(25)])[25 // 2]

    # Receive command
    buf = uart.read(2)

    if buf is not None:
        watchdog = 0
        data = [i for i in buf]

        command = data[0]
        header = data[1]

        if command == COMMAND_DICT["batt-voltage"]:
            sendMeasurement(str(battValue))

        elif command == COMMAND_DICT["current"]:
            sendMeasurement(str(currentValue))
        # elif command == COMMAND_DICT['temp1']:
        #     sendMeasurement(str(getTemp(temp1)))
        elif command == COMMAND_DICT["temp2"]:
            sendMeasurement(str(temp2Value))

        elif command == COMMAND_DICT["set-current"]:
            MODE = "current"
            targetCurrent = int.from_bytes(uart.read(header), "big") / 1000
            print("Set current to {}".format(targetCurrent))
        elif command == COMMAND_DICT["set-power"]:
            MODE = "power"
            targetPower = int.from_bytes(uart.read(header), "big") / 1000
            print("Set power to {}".format(targetPower))
    else:

        if watchdog > 10:
            print("Watchdog")
            targetCurrent = 0
        else:
            watchdog += 1

    if battValue > 0.1 and temp2Value < SHUTDOWN_TEMP:
        faultLed.value = False

        if temp2Value > THROTTLE_TEMP:
            powerLimit = max(0, min(MAX_POWER, calculatePowerLimit(temp2Value)))
        if MODE == "power":
            targetCurrent = targetPower / battValue
        elif MODE == "current":
            targetPower = targetCurrent * battValue

        outputCurrent = min(powerLimit / battValue, targetCurrent)
        error = int((outputCurrent - currentValue) * 2 ** 16 / 3.3)
        output += error
        output = min(max(output, 0), 2 ** 16 - 1)
        mos.value = output

    else:
        targetCurrent = 0
        faultLed.value = True
        mos.value = 0

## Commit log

2021-05-18 added code on board
2021-06-02 first implementation of constant power draw mode
2021-07-13 better graphs, fixed freezing on mouse event
    [main.py]
2021-07-14 test would run forever, fixed
    [main.py]
2021-07-15 so many things, better ESR stuff, configuration stuff, more buttons, etc
2021-07-15 separated gui updates from io updates to hopefully prevent OS from sleeping the program
    [main.py]
2021-07-17 all is good, problems were from non-native python environment
    [main.py]
2021-07-18 ESR measurement is faster, fixed unresolved current after error, improved feedback speed
    [main.py]
2021-07-18 human readable device selector, ESR is super fast and consistent
2021-07-18 automatically detects and connects to board, squashed some bugs
    [main.py]
